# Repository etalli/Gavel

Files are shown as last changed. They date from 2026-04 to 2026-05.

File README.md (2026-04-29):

# Gavel

[日本語](README.ja.md)

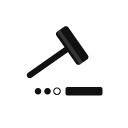
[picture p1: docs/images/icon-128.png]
Gavel icon


A physical controller for [Claude Code](https://claude.ai/code). · [Landing page](https://etalli.github.io/Gavel/)

**Why "Gavel"?** A judge's gavel makes decisions final — and here, the human is always the judge. Any keyboard could send the same keys, but a dedicated device makes you stop and think instead of pressing keys on autopilot. A ruling, not a reflex.
Gavel acts as a physical reminder and a friction layer against autopilot mode: pause, think, then decide.
Happy coding!
---

## What it does

- **Input** — Three physical buttons answer Claude Code's permission prompts (`1` Allow Once / `2` Always Allow / `3` Reject) without touching the keyboard.
- **Output** — LEDs light up in response to Claude Code hook events, giving real-time feedback on what Claude is doing. Color and pattern vary by tool risk category (read / write / network / destructive).
- **Log** — Every button press is appended to `~/.claude/gavel/decisions.jsonl` for decision history. Run `python3 hooks/stats.py` to see a summary.

---

## Hardware

The PCB is designed for the **Waveshare RP2040 Zero**.

| Board | LED output | Status |
|---|---|---|
| Waveshare RP2040 Zero | RGB NeoPixel (GP16) + 3× button LEDs (GP2/GP3/GP4) | Primary (PCB supported) |
| Raspberry Pi Pico | 3× discrete LEDs (GP2/GP3/GP4) | Legacy / DIY wiring only |

The NeoPixel shows the tool risk category color. The 3 button LEDs (one per switch) light up to confirm which button was pressed.

Board type is auto-detected — no manual configuration needed.

Both use the same GPIO pins for buttons (GP14/GP15/GP26). See [`hardware/wiring.md`](hardware/wiring.md) for full pin assignments.

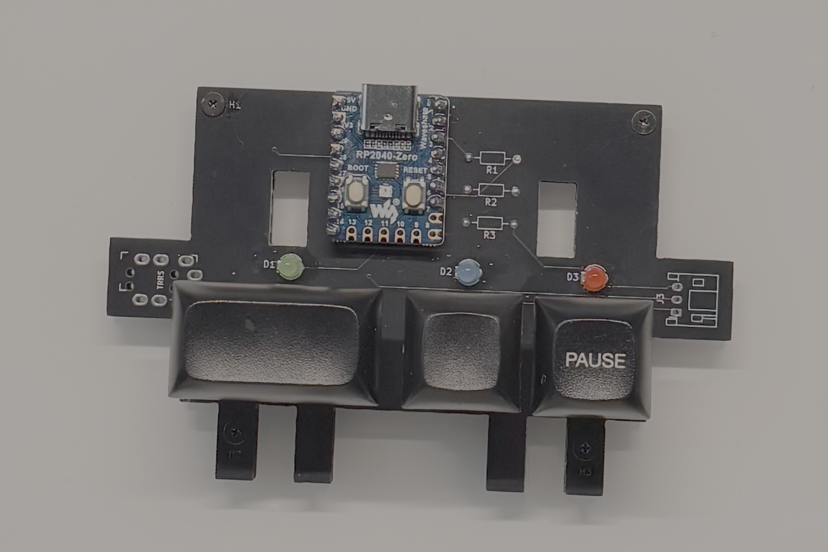
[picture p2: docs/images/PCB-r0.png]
PCB r0


---

## How it works

The microcontroller runs two independent roles over a single USB cable:

1. **USB HID keyboard** — pressing a button sends the matching keypress to the terminal. Claude Code receives it exactly as if the user typed it. No special Claude Code configuration needed.

2. **Serial listener** — Claude Code hooks call Python scripts on the Mac side, which send small JSON messages over the microcontroller's USB serial port to control the LEDs.

| Hook | Category | NeoPixel | Discrete LEDs |
|---|---|---|---|
| `PreToolUse` | readonly (Read / Grep / LS) | Blue | Center LED dim |
| `PreToolUse` | write (Edit / Write) | Yellow | Two LEDs dim |
| `PreToolUse` | network (WebFetch / Agent) | Orange blink | Blink |
| `PreToolUse` | destructive (Bash etc.) | Red | All bright |
| `PostToolUse` | — | Off | Off |
| `Notification` (info) | — | Single slow flash | Single slow flash |
| `Notification` (warn) | — | Three medium flashes | Three medium flashes |
| `Notification` (error) | — | Five fast red flashes | Five fast flashes |
| `PostToolUse` (context ≥ 90%) | — | Three medium flashes, then off | Three medium flashes, then off |

---

## Setup

### 1. Hardware Firmware
1. Install [CircuitPython](https://circuitpython.org) on your board
2. Download the [CircuitPython library bundle](https://circuitpython.org/libraries) matching your CircuitPython version
3. Copy the following to `CIRCUITPY/lib/`:
   - `adafruit_hid/` (folder) — required for all boards
   - `neopixel.mpy` — required for Waveshare RP2040 Zero only
4. Copy `firmware/boot.py` and `firmware/code.py` to the `CIRCUITPY` drive  
   *(Alternatively, run `./install.sh` to automate this step)*
5. **Power cycle** the board (unplug and replug USB) so `boot.py` takes effect
6. Wire buttons and LEDs per [`hardware/wiring.md`](hardware/wiring.md)

### 2. Software (Claude Code Hooks)
1. Install the Mac-side dependency: `pip3 install pyserial`
2. Add the project's hook scripts to your `~/.claude/settings.json` (instructions pending).
3. **Optional:** Run `./install.sh --deploy` to copy the hook scripts to a stable location (`~/.claude/gavel/`) and automatically update their paths in `settings.json`. This is recommended if you plan to move or rename the project folder.

---

## Troubleshooting

**LEDs do not respond when running hook scripts manually from the terminal**

```
No module named 'serial'
```

`pyserial` may not be installed for the `python3` used in your terminal session. Fix with:

```bash
pip3 install pyserial
```

Note: Claude Code hooks may use a different Python environment that already has `pyserial` installed, so hooks can work in a Claude Code session even when manual terminal tests fail.

---

## License

MIT License — see [LICENSE](LICENSE) for details.

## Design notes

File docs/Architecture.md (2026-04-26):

# Gavel Architecture

## System Overview

```
[Physical Device]               [Mac]
  Button 1 (Allow Once)   ──►  sends '1' to terminal
  Button 2 (Always Allow) ──►  sends '2' to terminal
  Button 3 (Reject)       ──►  sends '3' to terminal
  NeoPixel / LEDs         ◄──  Claude Code hooks → serial/USB → device
```

The device has two independent roles over a single USB cable:

1. **Input** — registers as a USB HID keyboard. When Claude Code shows a
   permission prompt, pressing a physical button sends the matching keypress.
   No special Claude Code configuration is required for this half.

2. **Output** — Claude Code's hooks system runs a Python script on the Mac
   for events like `PreToolUse`, `PostToolUse`, `Notification`, and `Stop`.
   Each script opens a serial connection to the device and sends a small JSON
   message that drives the LEDs.

---

## Two Core Integrations

### 1. Button Input → USB HID Keyboard

The device enumerates as a standard USB keyboard. Claude Code's interactive
permission prompts accept:

| Key | Meaning |
|-----|---|
| `1` | Allow Once |
| `2` | Always Allow  |
| `3` | Reject |

Pressing a physical button triggers the corresponding keypress via the
`adafruit_hid` CircuitPython library. The terminal (and Claude Code) receive
it exactly as if the user had typed it.

### 2. Notifications → Physical Feedback via Claude Code Hooks

Claude Code supports shell hooks that fire on lifecycle events. The hooks in
`.claude/settings.json` call Python scripts in `hooks/` which write JSON
over the device's serial port:

| Hook event | Script | Device response |
|---|---|---|
| PreToolUse | pre_tool.py | Color by category: blue (readonly), yellow (write), orange blink (network), red (destructive) |
| PostToolUse  | post_tool.py | Warn flash if context ≥ 90%, then all LEDs off |
| Notification | notify.py | Flash pattern based on level |
| Stop | stop.py | All LEDs off (session ended) |

Permission LEDs stay lit until a button is pressed — there is no timeout.

Each button press is appended to `~/.claude/gavel/decisions.jsonl` with a timestamp, enabling decision history and usage stats.

Notification flash patterns:

| Level | Pattern |
|---|---|
| info  | Single slow white flash |
| warn  | Three orange flashes |
| error | Five fast red flashes |

---

## Hardware

### Primary Target: Waveshare RP2040 Zero

| Component | Part | Notes |
|---|---|---|
| Microcontroller | Waveshare RP2040 Zero | RP2040, CircuitPython firmware |
| Buttons (×3) | 6×6mm tactile switch | Internal pull-up, active low, GP14/15/26 |
| Reset button | 6×6mm tactile switch | RESET pin to GND, no resistor |
| LED output | Built-in RGB NeoPixel | GP16 (WS2812), color-coded by tool risk category |
| Button LEDs (×3)| Discrete LEDs | GP2/GP3/GP4, one per button, confirm button press |
| Connection | USB-C cable | Powers the board + HID + serial |

### Also Supported (Auto-Detected)

| Board | LED output |
|---|---|
| Raspberry Pi Pico | 3× discrete LEDs (GP2/3/4) |
| Seeed XIAO RP2040 | Built-in RGB NeoPixel |

Board type is detected automatically at runtime via `board.board_id` — no
manual configuration needed.

See `hardware/wiring.md` for full pin assignments.

---

## File Layout

```
270_Gavel/
├── LICENSE                            ← MIT License
├── README.md                          ← Project overview and setup guide
├── README.ja.md                       ← Japanese translation of README
├── install.sh                         ← Installs hooks to ~/.claude/gavel/
├── firmware/
│   ├── boot.py                        ← Enables USB CDC console + data ports at startup
│   ├── code.py                        ← Button + LED + serial logic (main firmware)
│   ├── test_leds.py                   ← LED test script
│   └── requirements.txt               ← CircuitPython libs (adafruit_hid, neopixel)
├── hooks/
│   ├── find_device.py                 ← Locates the device's data serial port on macOS
│   ├── pico.py                        ← Shared serial send helper; reads button events → decisions.jsonl
│   ├── pre_tool.py                    ← Fires on PreToolUse — color by tool risk category
│   ├── post_tool.py                   ← Fires on PostToolUse — warn if context ≥ 90%, then idle
│   ├── notify.py                      ← Fires on Notification — drives flash pattern
│   ├── stop.py                        ← Fires on Stop — clears LEDs at session end
│   ├── test_hooks.py                  ← Hook test runner (no hardware needed)
│   ├── test_leds.py                   ← Sends each LED category to device for visual verification
│   └── requirements.txt               ← pip dependency: pyserial
├── hardware/
│   └── wiring.md                      ← GPIO pin assignments and wiring diagrams
└── docs/
    ├── Architecture.md                ← This file
    ├── behavior.md                    ← Detailed firmware behavior reference
    ├── ROADMAP.md                     ← Planned features by phase
    ├── index.html                     ← Project landing page
    ├── styles.css                     ← Landing page styles
    └── images/                        ← Icon files + PCB photo (SVG source + PNG exports)
```

---

## Setup Steps

1. Install CircuitPython on the board from circuitpython.org
2. Copy `firmware/boot.py` and `firmware/code.py` to the `CIRCUITPY` drive
3. Copy `adafruit_hid/` (all boards) and `neopixel.mpy` (RP2040 Zero) to `CIRCUITPY/lib/`
4. **Power cycle** the board (unplug and replug USB) so `boot.py` takes effect
5. Install the Mac-side dependency: `pip3 install pyserial`
6. Wire buttons per `hardware/wiring.md`
7. Run `./install.sh --deploy` to install hooks to `~/.claude/gavel/`
   and register them in `~/.claude/settings.json`

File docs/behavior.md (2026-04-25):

# Gavel Firmware Behavior Reference

This document explains in detail how `firmware/code.py` works — its state machine,
input handling, LED output, animation system, and serial protocol.

---

## Overview

```
                      ┌─────────────────────────────┐
                      │        firmware/code.py      │
                      │                              │
  Physical buttons ──►│  Button handler              │──► USB HID keypress (1/2/3)
                      │                              │
  Mac hook scripts ──►│  Serial reader → State FSM   │──► NeoPixel / PWM LEDs
                      │                              │
                      │  Animation tick (non-blocking)│
                      └─────────────────────────────┘
```

The firmware runs a **single tight loop** with no blocking delays in the main
path. Every periodic action (animations, timeouts) uses a timestamp comparison
rather than `time.sleep()`, so the loop stays responsive to buttons and serial
input at all times.

---

## Startup Sequence

```
1. board.board_id check  →  set USE_NEOPIXEL (True / False)
2. Keyboard + serial init
3. Button GPIO init       →  3× input with internal pull-up
4. LED init               →  NeoPixel or 3× PWM outputs
5. flash_all(times=2)     →  startup confirmation flash
6. Enter main loop
```

The startup flash (2× white blink) confirms that boot was successful and the
firmware is running. If the LEDs do not flash on power-up, `boot.py` has not
taken effect — unplug and replug USB.

---

## Board Auto-Detection

```python
USE_NEOPIXEL = board.board_id in ("waveshare_rp2040_zero", "seeeduino_xiao_rp2040")
```

`board.board_id` is a CircuitPython built-in string that identifies the
hardware at runtime. This eliminates any manual configuration. All subsequent
LED code branches on `USE_NEOPIXEL`:

- `True`  → NeoPixel path (single RGB LED on `board.NEOPIXEL`)
- `False` → PWM path (three separate LEDs on GP2 / GP3 / GP4)

---

## Config Block

All tunable parameters are grouped at the top of `code.py`:

| Constant | Default | Purpose |
|---|---|---|
| `BREATH_PERIOD` | 4.0 s | Duration of one full NeoPixel breathing cycle |
| `BREATH_MAX` | 125 | Peak brightness of the breathing animation (0–255) |
| `BREATH_UPDATE` | 100 ms  | How often the breathing brightness is recalculated |
| `KNIGHT_STEP_MS` | 1000 ms | Time each LED stays lit in the KITT sweep |
| `DEBOUNCE_MS` | 50 ms | Minimum time between registered button presses |
| `PERMISSION_TIMEOUT_MS` | 5000 ms | Auto-return to idle if no button is pressed |
| `KITT_DEFAULT` | `False` | Whether KITT / breathing animation starts enabled |

---

## State Machine

The firmware has two states:

```
        serial "permission"
  IDLE ──────────────────► PERMISSION
   ▲                            │
   │  button press              │  button press
   │  serial "idle"             │  serial "idle"
   │  timeout (5 s)             │  timeout (5 s)
   └────────────────────────────┘
```

### STATE_IDLE

Default state. LEDs are off (or running an animation if `kitt_enabled` is
`True`). The device is waiting for a hook event or user interaction.

### STATE_PERMISSION

Entered when the Mac sends `{"type": "permission"}` via serial (triggered by
a `PreToolUse` hook). The LEDs light up solid white to signal "waiting for
your decision." The state records the entry timestamp for timeout tracking.

**Transitions out of STATE_PERMISSION:**

| Trigger | Action |
|---|---|
| Button 1 pressed | Send keycode `1`, green flash, → IDLE |
| Button 2 pressed | Send keycode `2`, blue flash, → IDLE |
| Button 3 pressed | Send keycode `3`, red flash, → IDLE |
| Serial `{"type": "idle"}` | LEDs off, → IDLE |
| 5-second timeout | LEDs off, → IDLE (safety net) |

The timeout exists because `PostToolUse` may not fire in all edge cases
(e.g., if Claude Code is interrupted). Without it, the LEDs would stay solid
white indefinitely.

---

## Button Input Handling

### Single Button Press

Buttons are **active low**: the GPIO reads `False` (0) when pressed, because
the pin is pulled up internally and the button connects it to GND.

```
  Internal pull-up (3.3V)
       │
      [R]  (internal)
       │
  GPIO pin ──── button ──── GND
```

A press is registered only if `(now - last_press) > DEBOUNCE_MS` (50 ms),
preventing multiple triggers from contact bounce.

### Button 2 + Button 3 Combo (KITT Toggle)

Pressing Button 2 and Button 3 simultaneously toggles `kitt_enabled`.

**Detection algorithm:**

```
1. Either btn2 or btn3 reads as pressed
2. Wait 40 ms  (combo window)
3. Re-read both buttons
4. If BOTH are still pressed → combo action (toggle kitt_enabled)
5. If only one is pressed    → single button action
```

The 40 ms window is chosen to be long enough for human fingers (who cannot
press both buttons at exactly the same instant) but short enough that it feels
instantaneous. The combo also has its own 500 ms cooldown (`last_combo`) to
prevent double-toggle from a single press.

---

## LED Output

### NeoPixel (RP2040 Zero / XIAO RP2040)

A single WS2812 RGB LED. All states are expressed as `(R, G, B)` tuples with
values 0–255. The `brightness=1.0` parameter in the NeoPixel constructor means
the tuple values are used directly without scaling.

| Event | Color | RGB |
|---|---|---|
| Waiting (permission) | White | (255, 255, 255)|
| Allow Once pressed | Green | (0, 255, 0) |
| Always Allow pressed | Blue | (0, 0, 255) |
| Reject pressed | Red | (255, 0, 0) |
| Notification info | White pulse | (255, 255, 255)|
| Notification warn | Orange | (255, 165, 0)  |
| Notification error | Red rapid | (255, 0, 0) |
| Breathing (idle) | Blue fade | (0, 0, 0–125)  |

**`neo_flash(r, g, b, times, on_ms, off_ms)`**

A blocking helper used only for brief feedback flashes (200 ms or less total).
It is acceptable to block here because flashes are so short that no button
press or serial message will be missed.

### PWM LEDs (Raspberry Pi Pico)

Three separate LEDs driven by `pwmio.PWMOut` at 1 kHz. Duty cycle values:

| Constant | Value  | Meaning |
|---|---|---|
| `BRIGHT` | 65535  | Full brightness  |
| `DIM` | 8000 | Trail in KITT |
| `OFF` | 0 | LED off |

Each LED maps to a button:

| LED index | GPIO  | Color | Button |
|---|---|---|---|
| 0 | GP2 | Green | Allow Once |
| 1 | GP3 | Green | Always Allow  |
| 2 | GP4 | Red | Reject |

---

## Animation System

Both animations run **non-blocking** using a "next fire time" variable. Each
main loop iteration checks `now >= next_time`; if true, it updates the LED and
advances the timer. If false, the check costs only one integer comparison.

This pattern means the loop never sleeps, and buttons + serial remain
responsive during animations.

### NeoPixel Breathing (RP2040 Zero idle)

A smooth sine wave modulates the blue channel:

```python
brightness = int((1 - cos(2π × t / BREATH_PERIOD)) / 2 × BREATH_MAX)
```

- At `t=0`: `cos(0) = 1` → brightness = 0 (off)
- At `t=BREATH_PERIOD/2`: `cos(π) = -1` → brightness = BREATH_MAX (peak)
- Full cycle repeats every `BREATH_PERIOD` seconds (default 4 s)

The cosine formula produces a natural ease-in / ease-out that looks organic
rather than mechanical. Updated every `BREATH_UPDATE` ms (default 100 ms,
i.e. 10 fps — smooth enough for LED dimming).

**Active only when:** `USE_NEOPIXEL AND state == IDLE AND kitt_enabled`

### KITT Night-Rider Sweep (Pico idle)

Steps through the sequence `[0, 1, 2, 1]` (left → right → left) advancing
one LED every `KNIGHT_STEP_MS` ms (default 1000 ms).

```
Step 0: LED 0 BRIGHT,  LED 1 off,  LED 2 off
Step 1: LED 0 DIM,     LED 1 BRIGHT, LED 2 off
Step 2: LED 0 off,     LED 1 DIM,  LED 2 BRIGHT
Step 3: LED 0 off,     LED 1 BRIGHT, LED 2 DIM   ← bounce back
(repeat)
```

The previous LED is left at `DIM` (duty cycle 8000) rather than `OFF` to
create a tail/trail effect. Only one step behind is remembered (`knight_prev`),
so only one trail LED is shown at a time.

**Active only when:** `NOT USE_NEOPIXEL AND state == IDLE AND kitt_enabled`

---

## Serial Protocol (Mac → Device)

The Mac hook scripts send newline-terminated JSON strings over USB CDC serial.
The firmware reads one character at a time into a buffer, extracts complete
lines at each `\n`, and parses them with `json.loads()`.

### Message Format

```json
{"type": "<event>", "level": "<level>", "tool": "<name>"}
```

| Field | Required | Values |
|---|---|---|
| `type`  | yes | `"permission"`, `"notification"`, `"idle"` |
| `level` | for notification | `"info"`, `"warn"`, `"error"` |
| `tool`  | optional | tool name string from PreToolUse |

### Behavior per Message Type

**`"permission"`**
- Set `state = STATE_PERMISSION`
- Record `permission_time = now`
- Call `set_waiting_leds()` (solid white / all LEDs on)

**`"notification"`**
- Always transitions to `STATE_IDLE` after the flash
- `level == "error"` → 5× fast red flashes
- `level == "warn"`  → 3× orange flashes (NeoPixel) or 3× white flashes (Pico)
- `level == "info"`  → 1× slow white flash

**`"idle"`**
- Set `state = STATE_IDLE`
- Call `all_leds_off()`
- Reset KITT animation state (Pico only)

### Serial Buffer

```python
serial_buf = ""   # persistent across loop iterations

def read_serial_line():
    if not serial.in_waiting:
        return None
    char = serial.read(1).decode("utf-8")
    serial_buf += char
    if "\n" in serial_buf:
        line, serial_buf = serial_buf.split("\n", 1)
        return line.strip()
    return None
```

One character is read per loop iteration (if available). This keeps the loop
non-blocking — reading stops immediately if the port has no data. Complete
lines are returned only when a `\n` is received; partial lines remain in
`serial_buf` until the rest arrives.

---

## Mac-Side Hook Pipeline

```
Claude Code event
      │
      ▼
.claude/settings.json  →  calls hook script via shell
      │
      ▼
hooks/pre_tool.py (or notify.py, post_tool.py, stop.py)
      │   reads JSON from stdin (Claude Code passes event data)
      │   classifies notification level (notify.py only)
      │   checks context_window_utilization (post_tool.py only — warns if ≥ 90%)
      ▼
hooks/pico.py  →  send_to_pico(event, payload)
      │
      ▼
hooks/find_device.py  →  find_pico_port()
      │   scans /dev/tty.usbmodem* and /dev/tty.usbserial*
      │   returns the highest-sorted port (data port, not REPL console)
      ▼
pyserial  →  opens port, writes JSON + "\n", closes
      │
      ▼
firmware serial buffer  →  parsed and acted on
```

### Port Selection

CircuitPython's `usb_cdc.enable(console=True, data=True)` creates two serial
ports over one USB cable:

| Port suffix | Purpose |
|---|---|
| Lower number (e.g. `*1`) | REPL console  |
| Higher number (e.g. `*2`) | Data port (used by hooks) |

`find_pico_port()` always picks the last (highest-sorted) port, which is
reliably the data port.

### Notification Level Classification

`notify.py` classifies notifications by scanning the message text for keywords:

| Keywords found in message | Level |
|---|---|
| "error", "fail", "fatal" | error |
| "warn", "caution" | warn |
| (none of the above) | info |

This avoids depending on a `level` field that Claude Code does not always
provide in notification payloads.

---

## Main Loop Structure

```
while True:
    now = current time in ms

    ── Button input ──────────────────────────────────
    if debounce ok:
        if btn1 pressed:
            send keycode 1, flash green
        elif btn2 or btn3 pressed:
            wait 40 ms (combo window)
            re-read both
            if both: toggle kitt_enabled
            elif btn2: send keycode 2, flash blue
            elif btn3: send keycode 3, flash red

    ── Permission timeout ────────────────────────────
    if PERMISSION and elapsed > 5000 ms:
        → IDLE, leds off

    ── NeoPixel breathing tick ───────────────────────
    if NeoPixel AND IDLE AND kitt_enabled AND due:
        compute brightness from cosine
        set blue channel
        advance next tick time

    ── KITT tick ─────────────────────────────────────
    if NOT NeoPixel AND IDLE AND kitt_enabled AND due:
        advance knight_step
        set LEDs (bright current, dim previous)
        advance next tick time

    ── Serial input ──────────────────────────────────
    line = read one char from serial buffer
    if complete line:
        parse JSON
        act on type field
```

Each section is guarded so it only runs when meaningful, keeping the loop fast
and deterministic.

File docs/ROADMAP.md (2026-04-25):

# Gavel Roadmap

## Phase 1 — Polish

Quick wins requiring no new hardware. Focus on correctness and clean behavior.

| Issue | Title |
|---|---|
| [#3](https://github.com/etalli/Gavel/issues/3) | Stop hook: turn off LEDs when Claude Code session ends |
| [#6](https://github.com/etalli/Gavel/issues/6) | Remove misleading `BAUD_RATE` constant in `pico.py` |
| [#8](https://github.com/etalli/Gavel/issues/8) | Remove unused `press_enter()` from firmware |

## Phase 2 — Smarter Feedback

Richer visual feedback and decision logging. No new hardware required.

| Issue | Title |
|---|---|
| [#9](https://github.com/etalli/Gavel/issues/9) | Show last decision on LED after button press |
| [#4](https://github.com/etalli/Gavel/issues/4) | LED patterns per tool category in PreToolUse |
| [#5](https://github.com/etalli/Gavel/issues/5) | Reverse serial: log button decisions from Pico to Mac |

## Phase 3 — Hardware Expansion

New components and board support. Requires hardware changes.

| Issue | Title |
|---|---|
| — | Physical feedback: buzzer or haptic motor on GP13 (see `implementation_plan.md`) |
| [#10](https://github.com/etalli/Gavel/issues/10) | Solenoid support to animate Claude character on events |
| [#2](https://github.com/etalli/Gavel/issues/2) | Support alternative hardware (Seeed XIAO RP2040) |

---

## Out of Scope

| Issue | Title | Notes |
|---|---|---|
| [#1](https://github.com/etalli/Gavel/issues/1) | Add Japanese documentation | Separate from feature development |

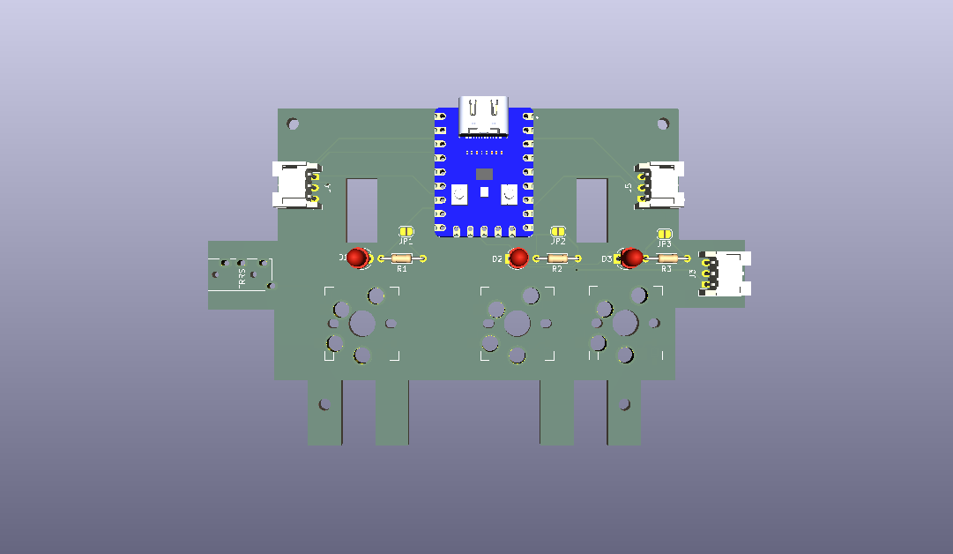
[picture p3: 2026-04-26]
docs/images/Gavel.png

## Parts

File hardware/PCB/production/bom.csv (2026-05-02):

Designator | Footprint | Quantity | Value | LCSC Part #
H1, H2, H3, H4 | MountingHole_2.2mm_M2 | 4 | MountingHole

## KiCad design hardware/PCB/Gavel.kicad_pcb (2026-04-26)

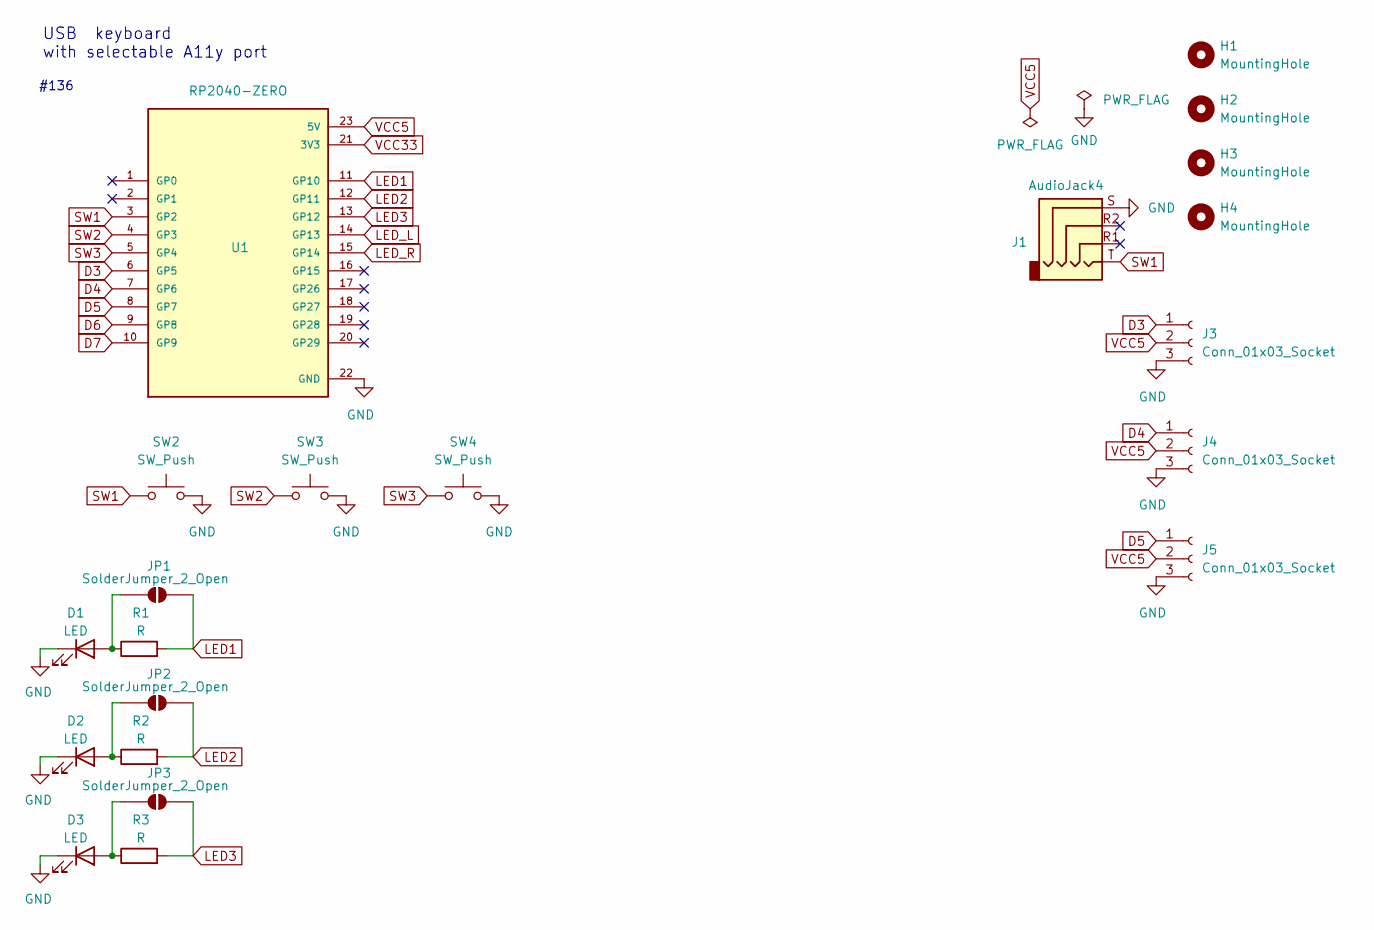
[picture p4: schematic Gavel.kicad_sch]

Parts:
D1, D2, D3: LED; LED_D3.0mm
H1, H2, H3, H4: MountingHole; MountingHole_2.2mm_M2
J1: AudioJack4; MJ-4PP-9_1side
J3, J4, J5: Conn_01x03_Socket; JST_PH_S3B-PH-K_1x03_P2.00mm_Horizontal
JP1, JP2, JP3: SolderJumper_2_Open; SolderJumper-2_P1.3mm_Open_RoundedPad1.0x1.5mm
R1, R2, R3: R; R_Axial_DIN0204_L3.6mm_D1.6mm_P7.62mm_Horizontal
SW2, SW3, SW4: SW_Push; k2_CherryMX_KailhChocV1_Socket_Diode-rev2
U1: RP2040-ZERO; MODULE_RP2040-ZERO; PARTREV NA

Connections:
D3: J3.1, U1.6 (GP5)
D4: J4.1, U1.7 (GP6)
D5: J5.1, U1.8 (GP7)
D6: U1.9 (GP8)
D7: U1.10 (GP9)
GND: D1.1 (K), D2.1 (K), D3.1 (K), J1.S, J3.3, J4.3, J5.3, SW2.2, SW3.2, SW4.2, U1.22 (GND)
LED1: JP1.2 (B), R1.2, U1.11 (GP10)
LED2: JP2.2 (B), R2.2, U1.12 (GP11)
LED3: JP3.2 (B), R3.2, U1.13 (GP12)
LED_L: U1.14 (GP13)
LED_R: U1.15 (GP14)
unnamed: D1.2 (A), JP1.1 (A), R1.1
unnamed: D2.2 (A), JP2.1 (A), R2.1
unnamed: D3.2 (A), JP3.1 (A), R3.1
SW1: J1.T, SW2.1, U1.3 (GP2)
SW2: SW3.1, U1.4 (GP3)
SW3: SW4.1, U1.5 (GP4)
VCC5: J3.2, J4.2, J5.2, U1.23 (5V)
VCC33: U1.21 (3V3)

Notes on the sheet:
USB keyboard with selectable A11y port
#136

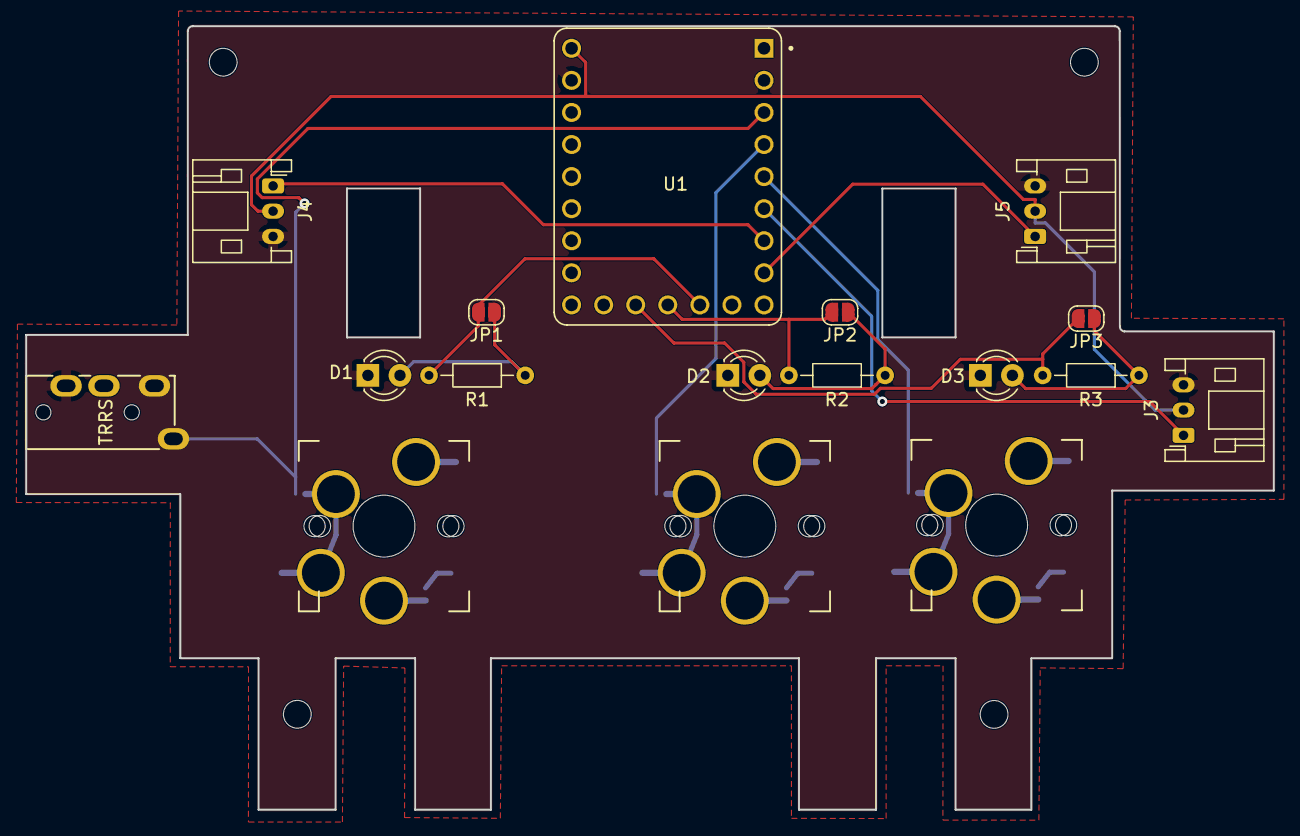
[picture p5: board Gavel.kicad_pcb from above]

Board: 2 copper layers, 98.8 x 62.1 mm, 21 parts (0 on the bottom side), 14 nets.

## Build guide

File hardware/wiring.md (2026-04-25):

# Gavel Wiring Reference

Both supported boards use the same GPIO numbers. Board type is auto-detected — no manual configuration needed.

| Board | LED output |
|---|---|
| Raspberry Pi Pico | 3× discrete LEDs on GP2/GP3/GP4 |
| Waveshare RP2040 Zero | Built-in RGB NeoPixel on GP16 + 3× discrete LEDs on GP2/GP3/GP4 |

---

## Buttons

Each button connects between a GPIO pin and GND.
The internal pull-up is used — no external resistor needed.

| Button | GPIO |
|---|---|
| Allow Once | GP14 |
| Always Allow | GP15 |
| Reject | GP26 |

Wiring per button:
```
GPIO pin ──[button]── GND
```

## LEDs — Raspberry Pi Pico

Each LED needs a 220Ω resistor in series.

| LED | Pico Pin | GPIO | Color |
|---|---|---|---|
| Allow Once | Pin 4 | GP2  | Green |
| Always Allow | Pin 5 | GP3  | Green |
| Reject | Pin 6 | GP4  | Red |

```
GPIO pin ──[220Ω]──[LED anode → cathode]── GND
```

## LEDs — Waveshare RP2040 Zero

The RP2040 Zero drives both the built-in RGB NeoPixel (GP16) and three discrete LEDs (GP2/GP3/GP4) simultaneously.

### Discrete LEDs

Same pin assignment and wiring as the Pico. Each LED needs a 220Ω resistor in series.

| LED | GPIO | Color |
|---|---|---|
| Allow Once | GP2  | Green |
| Always Allow | GP3  | Green |
| Reject | GP4  | Red |

```
GPIO pin ──[220Ω]──[LED anode → cathode]── GND
```

### NeoPixel (built-in)

No external LEDs or resistors needed.

Color coding:

| Event | Color |
|---|---|
| Waiting for input | White |
| Allow Once pressed | Green |
| Always Allow pressed | Blue |
| Reject pressed | Red |
| Notification (info) | White pulse |
| Notification (warn) | Orange flash |
| Notification (error) | Red rapid flash |
| Breathing (idle, optional) | Blue fade in/out |

## Reset Button

Connecting a momentary button between the RUN pin and GND resets the firmware without unplugging USB.

| Button | GPIO | Notes |
|---|---|---|
| Reset  | RUN (Pin 30 on Pico) | Connect to GND momentarily |

No resistor needed — internal pull-up on RUN.

```
RUN ──[button]── GND
```

## Serial (USB)

The board communicates with the Mac over USB — no extra wires needed.

CircuitPython's `usb_cdc` exposes two serial ports over the same USB cable:

| Port | Purpose |
|---|---|
| `/dev/tty.usbmodem*1` | REPL console |
| `/dev/tty.usbmodem*2` | Data port used by hook scripts |

The hook scripts on the Mac write JSON commands to the data port; the firmware reads them and controls the LEDs.

## Power

The Pico is powered entirely from the USB cable connected to the Mac.
No separate power supply needed.

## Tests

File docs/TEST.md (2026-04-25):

# Gavel Kit Test Checklist

Work through each section in order. All steps must pass before shipping or using the device.

---

## 1. PCB Inspection (Before Soldering)

Visual checks before applying any heat:

- [ ] No visible shorts between adjacent pads (use a magnifier if needed)
- [ ] All pads are clean — no oxidation or solder mask damage
- [ ] Top plate aligns correctly over the main PCB

---

## 2. Firmware Flash

**Goal:** Confirm the RP2040-Zero accepts firmware.

1. Hold the **BOOT** button on the RP2040-Zero
2. Plug the USB cable into your Mac while holding BOOT
3. Release BOOT — a drive named `RPI-RP2` should appear in Finder
4. Drag the CircuitPython `.uf2` file onto `RPI-RP2`
5. The drive will disappear and reappear as `CIRCUITPY`

- [ ] `RPI-RP2` appears when entering bootloader mode
- [ ] `CIRCUITPY` drive mounts after flashing

---

## 3. Library and Firmware Files

Copy required files to `CIRCUITPY`:

| File / Folder | Destination |
|---|---|
| `adafruit_hid/` | `CIRCUITPY/lib/adafruit_hid/` |
| `neopixel.mpy` | `CIRCUITPY/lib/neopixel.mpy` |
| `firmware/boot.py` | `CIRCUITPY/boot.py` |
| `firmware/code.py` | `CIRCUITPY/code.py` |

After copying, **power cycle** (unplug and replug USB).

- [ ] All files copied without error
- [ ] Board reboots cleanly after power cycle

---

## 4. LED Self-Test (Idle State)

With the board powered and `code.py` running:

- [ ] The built-in RGB NeoPixel lights up **white** (waiting for input state)

If the LED stays off or shows an unexpected color, confirm your board is a supported NeoPixel board — board type is auto-detected from the board ID.

---

## 5. Button Test — USB HID

**Goal:** Each button sends the correct keypress to the Mac.

1. Open any text editor on your Mac (e.g., TextEdit)
2. Click inside the document so it has focus
3. Press each button on Gavel one at a time

| Button | Expected keypress | Expected LED color |
|---|---|---|
| Allow Once | `1` | Green |
| Always Allow | `2` | Blue |
| Reject | `3` | Red |

- [ ] Allow Once sends `1` and LED turns green
- [ ] Always Allow sends `2` and LED turns blue
- [ ] Reject sends `3` and LED turns red
- [ ] LED returns to white after ~1 second

---

## 6. Serial Port Detection

**Goal:** Confirm the Mac can see both USB serial ports.

Run in Terminal:

```sh
ls /dev/tty.usbmodem*
```

Expected output: two ports, for example:

```
/dev/tty.usbmodem1101
/dev/tty.usbmodem1103
```

- [ ] Two `tty.usbmodem*` ports appear

---

## 7. Hook Integration Test

**Goal:** Confirm Claude Code hooks trigger LED responses.

1. Run `./install.sh --deploy` to register hooks
2. Start a Claude Code session
3. Ask Claude to run any tool (e.g., `list files`)

| Hook event | Expected LED behavior |
|---|---|
| `PreToolUse` (permission prompt) | All LEDs solid on |
| `PostToolUse` (after tool runs) | All LEDs off → return to white |
| `Notification` (warn) | Three medium flashes |
| `Notification` (error) | Five fast red flashes |

- [ ] LED responds to `PreToolUse`
- [ ] LED responds to `PostToolUse`
- [ ] Notification events produce correct flash patterns

---

## 8. Reset Button Test

1. Press the **RESET** button on the RP2040-Zero
2. The board should reboot and the NeoPixel should return to white within 3 seconds

- [ ] Reset button reboots the board cleanly
- [ ] Firmware restarts without needing to replug USB

---

## Pass Criteria

All checkboxes above must be checked before the kit is considered ready to ship or use.

If any step fails, refer to [`hardware/wiring.md`](hardware/wiring.md) for pin assignments and [`README.md`](README.md) for setup instructions.

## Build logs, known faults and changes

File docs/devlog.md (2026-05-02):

# Gavel Dev Log

---

## 2026-05-03

- **feat:** long press macro — hold 800ms to type configurable string per button (issue #38, v1.0.8)
- **feat:** v3 PCB confirmed working — buttons GP2/3/4, LEDs GP10/11/12, servo GP6 (v1.0.7)
- **refactor:** pin assignments moved to very top of config block in `code.py`
- **pending:** GP5 vibration motor not yet tested on v3 PCB (issue #35); top plate not yet ordered

---

## 2026-05-01

### Codex Review — working tree diff

**Target:** working tree (modified KiCad PCB files + untracked devlog/gerbers)

**Finding — P1:**

> `hardware/PCB/Gavel-TopPlate.kicad_pcb` lines 61–62
>
> The KiCad board's saved plot configuration now targets only `Edge.Cuts` and a non-Gerber output format (`outputformat` changed from `1` → `5`). Regenerating fabrication outputs from the committed design will produce only an SVG of the board outline, losing the full copper/mask/silkscreen Gerber set. This is a workflow-breaking regression for the hardware release process.

**Action:** Opened [issue #36](https://github.com/etalli/Gavel/issues/36) — later confirmed false alarm and closed. Edge.Cuts SVG output is intentional: it is the laser-cut design file for the top plate acrylic. Plot config is correct.

---

## 2026-04-29

- **feat:** added `stats.py` CLI — reads `~/.claude/gavel/decisions.jsonl` and prints per-button counts, reject rate, and first/last timestamps
- **docs:** updated README to mention `stats.py` and decision log

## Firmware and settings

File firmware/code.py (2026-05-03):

"""
Gavel – Claude Code physical controller
Waveshare RP2040-Zero, Raspberry Pi Pico firmware (CircuitPython)

Buttons:
  GP2  → Allow Once / GP3  → Always Allow / GP4  → Reject

LEDs:
  GP10 → Allow Once (green) / GP11 → Always Allow (green) / GP12 → Reject (red)

NeoPixel (Waveshare RP2040 Zero):
  GP16 → RGB NeoPixel — color-coded per event

Vibration motor (Waveshare RP2040 Zero):
  GP5 → motor driver IN — active high

Servo (Waveshare RP2040 Zero):
  GP6 → servo signal — holds angle by notification severity
         idle=0°  info=45°  warn=90°  error=135°

Serial: USB serial (/dev/tty.usbmodem*) from Mac hook scripts
  Incoming JSON: {"type": "notification"|"permission"|"idle", "level": "info"|"warn"|"error"}
"""

import board
import digitalio
import json
import math
import pwmio
import time
import usb_cdc
import usb_hid
from adafruit_hid.keyboard import Keyboard
from adafruit_hid.keyboard_layout_us import KeyboardLayoutUS
from adafruit_hid.keycode import Keycode

# ── Config ────────────────────────────────────────────────────

# Pin assignments — edit here when adapting to a different board
PIN_BTN_ALLOW_ONCE   = board.GP2
PIN_BTN_ALWAYS_ALLOW = board.GP3
PIN_BTN_REJECT       = board.GP4
PIN_LED_ALLOW_ONCE   = board.GP10
PIN_LED_ALWAYS_ALLOW = board.GP11
PIN_LED_REJECT       = board.GP12
PIN_MOTOR            = board.GP5
PIN_SERVO            = board.GP6
PIN_EYE_L            = board.GP0
PIN_EYE_R            = board.GP1

# Board auto-detection — no manual change needed
# NeoPixel boards: Waveshare RP2040 Zero, Seeed XIAO RP2040
# Discrete LED boards: Raspberry Pi Pico, Pico W (default)
USE_NEOPIXEL = board.board_id in ("waveshare_rp2040_zero", "seeeduino_xiao_rp2040")

# NeoPixel breathing animation
BREATH_PERIOD = 4.0   # seconds per full breath cycle
BREATH_MAX    = 125    # peak brightness (0–255)
BREATH_UPDATE = 100    # ms between brightness updates

# KITT animation (Pico only)
KNIGHT_STEP_MS = 1000  # ms per LED step

# Button debounce — guards against electrical bounce on the falling edge only
DEBOUNCE_MS = 50

# How long to hold the pressed button's LED after a decision
DECISION_HOLD_MS = 2_000

# KITT / breathing mode — toggle with Button 2 + Button 3 simultaneously
KITT_DEFAULT = False

# Permission blink interval for network-category tools (ms)
NETWORK_BLINK_MS = 500

# Servo angles per notification severity (degrees, 0–180)
SERVO_IDLE  =   0
SERVO_INFO  =  45
SERVO_WARN  =  90
SERVO_ERROR = 135

# Long press — hold duration and macro strings (one per button)
LONG_PRESS_MS      = 800
MACRO_ALLOW_ONCE   = "SGTM"
MACRO_ALWAYS_ALLOW = "HELLO WORLD"
MACRO_REJECT       = "NOPE"
MACROS = [MACRO_ALLOW_ONCE, MACRO_ALWAYS_ALLOW, MACRO_REJECT]

# ── USB Keyboard ──────────────────────────────────────────────
kbd    = Keyboard(usb_hid.devices)
layout = KeyboardLayoutUS(kbd)

def type_string(text):
    layout.write(text)

# ── USB Serial data port (separate from REPL console) ────────
serial = usb_cdc.data

# ── Servo (50 Hz PWM) ────────────────────────────────────────
# Pulse width: 1 ms (0°) to 2 ms (180°) over a 20 ms period.
_servo_pwm = pwmio.PWMOut(PIN_SERVO, frequency=50)

def set_servo(angle):
    pulse_us = 1000 + int(angle / 180 * 1000)  # 1000–2000 µs
    _servo_pwm.duty_cycle = pulse_us * 65535 // 20000

set_servo(SERVO_IDLE)

# ── Vibration motor (active high) ────────────────────────────
motor = digitalio.DigitalInOut(PIN_MOTOR)
motor.direction = digitalio.Direction.OUTPUT
motor.value = False

def buzz(times=1, on_ms=60, off_ms=60):
    for _ in range(times):
        motor.value = True
        time.sleep(on_ms / 1000)
        motor.value = False
        time.sleep(off_ms / 1000)

# ── Buttons (active low via internal pull-up) ─────────────────
def make_button(pin):
    b = digitalio.DigitalInOut(pin)
    b.direction = digitalio.Direction.INPUT
    b.pull = digitalio.Pull.UP
    return b

btn_allow_once   = make_button(PIN_BTN_ALLOW_ONCE)
btn_always_allow = make_button(PIN_BTN_ALWAYS_ALLOW)
btn_reject       = make_button(PIN_BTN_REJECT)

# Each entry: (button_object, keycode, NeoPixel_color, discrete_LED_index, name)
BUTTONS = [
    (btn_allow_once,   Keycode.ONE,   (0, 255, 0), 0, "allow_once"),
    (btn_always_allow, Keycode.TWO,   (0, 0, 255), 1, "always_allow"),
    (btn_reject,       Keycode.THREE, (255, 0, 0), 2, "reject"),
]

# ── LED setup ─────────────────────────────────────────────────
# Both boards: anode → GPIO, cathode → GND (active-high): GPIO HIGH = on.
BRIGHT = 65535
DIM    = 8000
OFF    = 0

def make_led(pin):
    return pwmio.PWMOut(pin, frequency=1000, duty_cycle=OFF)

led_allow_once   = make_led(PIN_LED_ALLOW_ONCE)
led_always_allow = make_led(PIN_LED_ALWAYS_ALLOW)
led_reject       = make_led(PIN_LED_REJECT)
LEDS   = [led_allow_once, led_always_allow, led_reject]

if USE_NEOPIXEL:
    import neopixel
    np    = neopixel.NeoPixel(board.NEOPIXEL, 1, brightness=1.0, auto_write=True, pixel_order=neopixel.RGB)
    eye_l = neopixel.NeoPixel(PIN_EYE_L,      1, brightness=1.0, auto_write=True)
    eye_r = neopixel.NeoPixel(PIN_EYE_R,      1, brightness=1.0, auto_write=True)
    breath_next = 0

def set_np(color):
    if USE_NEOPIXEL:
        np[0]    = color
        eye_l[0] = color
        eye_r[0] = color

KNIGHT_SEQUENCE = [0, 1, 2, 1]
knight_step = 0
knight_prev = -1
knight_next = 0

def all_leds_off():
    set_np((0, 0, 0))
    for led in LEDS:
        led.duty_cycle = OFF

def set_led(index, duty):
    LEDS[index].duty_cycle = duty

def set_permission_leds(category):
    """Set LEDs based on tool risk category.
    destructive → all bright red  (high alert)
    write       → two LEDs dim    (medium risk)
    readonly    → one LED dim     (low stakes)
    network     → handled by blink loop in main
    """
    all_leds_off()
    if category == "readonly":
        set_np((0, 0, 255))        # blue
        set_led(1, DIM)
    elif category == "write":
        set_np((255, 200, 0))      # yellow
        set_led(0, DIM)
        set_led(1, DIM)
    elif category == "network":
        pass  # blink loop takes over immediately
    else:  # destructive (default)
        set_np((255, 0, 0))        # red
        for led in LEDS:
            led.duty_cycle = BRIGHT

def flash_all(times=3, on_ms=80, off_ms=80):
    for _ in range(times):
        set_np((255, 255, 255))
        for led in LEDS:
            led.duty_cycle = BRIGHT
        time.sleep(on_ms / 1000)
        set_np((0, 0, 0))
        for led in LEDS:
            led.duty_cycle = OFF
        time.sleep(off_ms / 1000)

# ── Notification flash helper ─────────────────────────────────
def flash_for_level(level):
    all_leds_off()
    if level == "error":
        buzz(times=3, on_ms=60, off_ms=60)
        for _ in range(5):
            set_np((255, 0, 0))
            set_led(2, BRIGHT)
            time.sleep(0.1)
            set_np((0, 0, 0))
            set_led(2, OFF)
            time.sleep(0.1)
    elif level == "warn":
        for _ in range(3):
            set_np((255, 165, 0))  # orange
            for led in LEDS:
                led.duty_cycle = BRIGHT
            time.sleep(0.2)
            set_np((0, 0, 0))
            for led in LEDS:
                led.duty_cycle = OFF
            time.sleep(0.08)
    else:
        flash_all(times=1, on_ms=200)

# ── Serial helpers ────────────────────────────────────────────
serial_buf = ""

def read_serial_line():
    global serial_buf
    if not serial.in_waiting:
        return None
    try:
        char = serial.read(1).decode("utf-8")
        if char:
            serial_buf += char
            if "\n" in serial_buf:
                line, serial_buf = serial_buf.split("\n", 1)
                return line.strip()
    except Exception:
        pass
    return None

def send_key(keycode):
    kbd.press(keycode)
    time.sleep(0.05)
    kbd.release_all()
    time.sleep(0.05)

button_event_queue = []  # buffered when port is closed; flushed on next connection

def press_button(keycode, color, led_idx, name="unknown"):
    all_leds_off()
    set_servo(SERVO_IDLE)
    buzz(times=1, on_ms=60)
    send_key(keycode)
    set_np(color)
    set_led(led_idx, BRIGHT)
    button_event_queue.append(json.dumps({"event": "button", "button": name}) + "\n")

# ── Startup flash ─────────────────────────────────────────────
flash_all(times=2, on_ms=100, off_ms=100)

# ── State ─────────────────────────────────────────────────────
STATE_IDLE       = "idle"
STATE_PERMISSION = "permission"
state = STATE_IDLE

kitt_enabled = KITT_DEFAULT  # runtime toggle; default set in config block above

# ── Main loop ─────────────────────────────────────────────────
last_press       = 0
last_combo       = 0
decision_off_at  = 0     # ms timestamp to clear the decision LED; 0 = inactive
waiting_release  = False  # True = block until all buttons are physically released
btn_down_idx     = -1    # BUTTONS index of held button; -1 = none pending
btn_down_at      = 0     # ms when the current button first went down
perm_category    = "destructive"  # category of the current permission request
perm_blink_on    = False          # current blink state for network category
perm_blink_next  = 0              # next blink toggle timestamp (ms)

while True:
    now = time.monotonic_ns() // 1_000_000  # ms

    # ── Button input ──────────────────────────────────────────
    all_released = btn_allow_once.value and btn_always_allow.value and btn_reject.value
    if waiting_release:
        if all_released:
            waiting_release = False
            btn_down_idx = -1
            btn_down_at  = 0

    elif btn_down_idx >= 0:
        # Button held — resolve as long or short press
        if BUTTONS[btn_down_idx][0].value:  # released → short press
            press_button(*BUTTONS[btn_down_idx][1:])
            decision_off_at = now + DECISION_HOLD_MS
            state = STATE_IDLE
            last_press = now
            waiting_release = True
        elif (now - btn_down_at) >= LONG_PRESS_MS:  # held long enough → macro
            type_string(MACROS[btn_down_idx])
            last_press = now
            waiting_release = True

    elif (now - last_press) > DEBOUNCE_MS:
        if not btn_allow_once.value:
            btn_down_idx = 0
            btn_down_at  = now
            last_press   = now

        elif not btn_always_allow.value or not btn_reject.value:
            # Wait 40ms to see if both get pressed (combo window)
            time.sleep(0.04)
            b2 = not btn_always_allow.value
            b3 = not btn_reject.value

            if b2 and b3:
                # Combo: toggle KITT / breathing mode (immediate, no long press)
                if (now - last_combo) > 500:
                    kitt_enabled = not kitt_enabled
                    if not kitt_enabled:
                        all_leds_off()
                    last_combo = now
                last_press = now
                waiting_release = True
            elif b2:
                btn_down_idx = 1
                btn_down_at  = now
                last_press   = now
            elif b3:
                btn_down_idx = 2
                btn_down_at  = now
                last_press   = now

    # ── Decision LED hold ─────────────────────────────────────
    if decision_off_at and now >= decision_off_at:
        all_leds_off()
        decision_off_at = 0

    # ── Network permission blink (non-blocking) ───────────────
    if state == STATE_PERMISSION and perm_category == "network" and now >= perm_blink_next:
        perm_blink_on = not perm_blink_on
        if perm_blink_on:
            set_np((255, 165, 0))  # orange
            for led in LEDS:
                led.duty_cycle = BRIGHT
        else:
            all_leds_off()
        perm_blink_next = now + NETWORK_BLINK_MS

    # ── NeoPixel breathing (sine wave, non-blocking) ──────────
    if USE_NEOPIXEL and state == STATE_IDLE and kitt_enabled and not decision_off_at and now >= breath_next:
        t = time.monotonic()
        brightness = int((1 - math.cos(2 * math.pi * t / BREATH_PERIOD)) / 2 * BREATH_MAX)
        set_np((0, 0, brightness))
        breath_next = now + BREATH_UPDATE

    # ── KITT animation (regular LEDs only, non-blocking) ──────
    if not USE_NEOPIXEL and state == STATE_IDLE and kitt_enabled and not decision_off_at and now >= knight_next:
        all_leds_off()
        curr = KNIGHT_SEQUENCE[knight_step]
        if knight_prev >= 0 and knight_prev != curr:
            set_led(knight_prev, DIM)
        set_led(curr, BRIGHT)
        knight_prev = curr
        knight_step = (knight_step + 1) % len(KNIGHT_SEQUENCE)
        knight_next = now + KNIGHT_STEP_MS

    # ── Incoming serial from Mac ──────────────────────────────
    line = read_serial_line()
    if line:
        # Flush buffered button events first — port is confirmed open
        if button_event_queue:
            for evt in button_event_queue:
                serial.write(evt.encode())
            button_event_queue.clear()
        print("received:", line)
        try:
            msg = json.loads(line)
            msg_type = msg.get("type", "")
            level    = msg.get("level", "info")

            if msg_type == "permission":
                state = STATE_PERMISSION
                decision_off_at = 0
                perm_category   = msg.get("category", "destructive")
                perm_blink_on   = False
                perm_blink_next = now
                buzz(times=2, on_ms=60, off_ms=60)
                set_permission_leds(perm_category)

            elif msg_type == "notification":
                angle = {
                    "error": SERVO_ERROR,
                    "warn":  SERVO_WARN,
                }.get(level, SERVO_INFO)
                set_servo(angle)
                flash_for_level(level)
                state = STATE_IDLE
                if not USE_NEOPIXEL:
                    knight_prev = -1
                    knight_next = now + KNIGHT_STEP_MS

            elif msg_type == "idle":
                state = STATE_IDLE
                set_servo(SERVO_IDLE)
                all_leds_off()
                if not USE_NEOPIXEL:
                    knight_prev = -1
                    knight_next = now + KNIGHT_STEP_MS

        except (ValueError, KeyError) as e:
            print("JSON error:", e, "line:", line)

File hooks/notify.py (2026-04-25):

#!/usr/bin/env python3
"""
Claude Code hook: Notification event
Forwards Claude Code notifications to the Pico as LED signals.
"""
import json
import sys
import os

sys.path.insert(0, os.path.dirname(__file__))
from pico import send_to_pico


def main():
    try:
        data = json.load(sys.stdin)
    except (json.JSONDecodeError, EOFError):
        data = {}

    message = data.get("message", "")
    if any(w in message.lower() for w in ("error", "fail", "fatal")):
        level = "error"
    elif any(w in message.lower() for w in ("warn", "caution")):
        level = "warn"
    else:
        level = "info"

    send_to_pico("Notification", {"type": "notification", "level": level, "message": message})


if __name__ == "__main__":
    main()

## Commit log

2026-04-25 docs: add landing page link to README
2026-04-25 docs: add Japanese landing page with language switcher
2026-04-25 docs: add language switcher at top of landing pages
2026-04-25 docs: update footer text for clarity in Japanese landing page
2026-04-25 feat: hold decision LED for 2s after button press (#25)
    * docs: improve Why Gavel section in README (EN + JA)
    * docs: add Happy coding! to Why Gavel section
    * feat: hold decision LED for 2s after button press (fix #9)
    [code.py]
2026-04-25 fix: move decision_off_at out of press_button to fix button detection during permission state
    [code.py]
2026-04-25 fix: raise DEBOUNCE_MS to 300 to prevent chattering after fast press_button return
    [code.py]
2026-04-25 fix: require button release before next press to eliminate chattering
    [code.py]
2026-04-25 feat: LED patterns per tool category in PreToolUse (Close #4) (#28)
2026-04-25 feat: tool-specific NeoPixel colors per risk category (#30)
    * feat: tool-specific NeoPixel colors per risk category (Close #17)
    readonly → blue, write → yellow (two LEDs dim), destructive → red.
    Adds WRITE_TOOLS set (Edit/Write/MultiEdit/NotebookEdit) to pre_tool.py
    so file-modifying tools show yellow instead of full-alert red.
    * feat: add test_leds.py to manually verify all LED patterns
2026-04-25 feat: log button decisions from Pico to Mac (Close #5) (#29)
    Pico writes {"event":"button","button":"allow_once|always_allow|reject"}
    to serial on each press. The next hook call drains the buffer and appends
    timestamped events to ~/.claude/gavel/decisions.jsonl.
2026-04-25 docs: update README with LED color categories and decision log
2026-04-25 docs: sync README.ja.md with LED color categories and decision log
2026-04-26 feat: remove permission timeout — LEDs stay lit until button pressed (Close #32)
2026-04-26 docs: RP2040 Zero is primary board, Pico noted as legacy
2026-04-26 docs: PCB has NeoPixel + 3 button LEDs, clarify each LED's role
2026-04-26 docs: update Architecture.md — LED categories, button LEDs, decision log, no timeout
2026-04-26 fix: buffer button events when serial port closed, flush on reconnect (Close #34)
    [code.py]
2026-04-26 fix: flush button queue on message receipt; add 200ms read delay in pico.py
    [code.py, pico.py]
2026-04-26 fix: always queue button events, flush on next message receipt
    [code.py]
2026-04-26 Update .gitignore
    Delete ~Gavel-TopPlate.kicad_pro.lck
    a
2026-04-26 ORDERED JLCPCB
    [Gavel-TopPlate.kicad_pcb, Gavel.kicad_pcb, Gavel.kicad_sch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]
2026-04-30 feat: add vibration motor support on GP5
    - buzz() helper: configurable pulses (times, on_ms, off_ms)
    - 2 pulses on permission request (alert)
    - 1 pulse on button press (confirmation)
    - 3 pulses on error notification
    [code.py]
2026-04-30 test: add vibration motor test script (GP5)
    [test_motor.py]
2026-05-01 docs: correct devlog — issue #36 was false alarm (SVG is laser-cut file)
2026-05-02 feat: servo angle encodes notification severity on GP6 (Close #37)
    - set_servo(angle) helper: maps 0-180° to 1-2ms pulse at 50Hz
    - idle=0°, info=45°, warn=90°, error=135°
    - servo resets to 0° on button press and idle message
    - moved pwmio import to top-level
    [code.py]
2026-05-02 test: add servo test script (GP6)
2026-05-02 fix: always write hook.log in send_to_pico, not only on error
    [pico.py]
2026-05-02 release: v1.0.6 — servo notification indicator
2026-05-02 feat: v3 PCB pin reassignment — buttons GP2/3/4, LEDs GP10/11/12
    v2: buttons GP14/15/26, LEDs GP2/3/4
    v3: buttons GP2/3/4, LEDs GP10/11/12
    Update docstring and production files (BOM, designators, netlist, positions)
    [bom.csv, designators.csv, positions.csv]
2026-05-02 release: v1.0.7 — v3 PCB pin reassignment
2026-05-02 refactor: remove v2 board pin comments, v3 only
2026-05-02 refactor: move pin assignments to config block at top
2026-05-02 refactor: move pin assignments to very top of config block
2026-05-02 feat: long press macro — hold 800ms to type MACROS string (Close #38)
    - KeyboardLayoutUS added for string typing
    - btn_down_idx/btn_down_at state tracks held button non-blocking
    - short press (<800ms) → existing keycode behavior
    - long press (>=800ms) → type_string(MACROS[btn])
    - combo (B2+B3) unchanged — immediate KITT toggle
    [code.py]
2026-05-02 chore: update macro strings for each button
2026-05-02 release: v1.0.8 — long press macro
